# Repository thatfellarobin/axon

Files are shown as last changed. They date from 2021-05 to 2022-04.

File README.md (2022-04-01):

# Axon
[][cc-by-nc-sa]

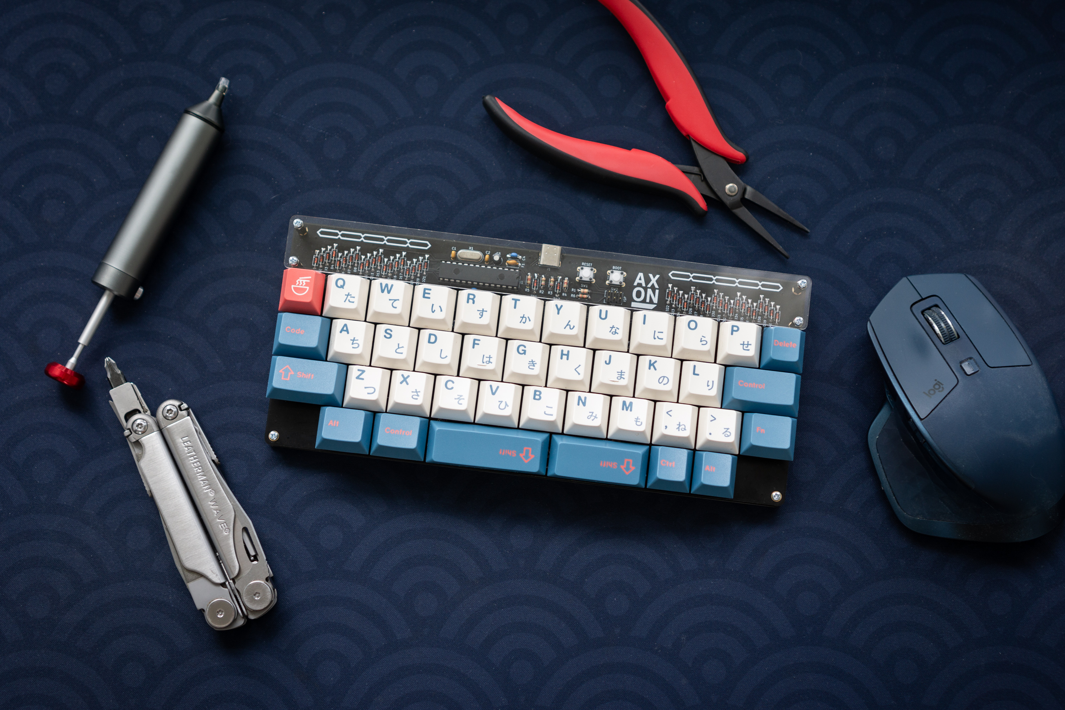
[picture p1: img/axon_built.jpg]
Built Axon

*Axon version 1.0 built with Durock T1 and GMK Bento*

⚠️ **Using the live github version is not recommended. Please use [a release](https://github.com/thatfellarobin/axon/releases) instead. Performance is not guaranteed outside of official sale (which have not existed so far).**

Axon is a 40% custom mechanical keyboard with an emphasis on symmetrically placed through-hole components, inspired by other keyboards such as [gingham](https://github.com/yiancar/gingham_pcb) and [plaid](https://github.com/hsgw/plaid). Axon runs on an ATmega328P using VUSB and QMK.

Notable features include an [HHKB-style](https://happyhackingkb.com/) layout with missing lower corners, and a split spacebar. I never use my right thumb to hit spacebar, so the split allows me to use my right thumb to access additional keyboard layers. A full write-up can be found [on my website](https://www.robinliu.me/axon).

### Images

**Layout:**

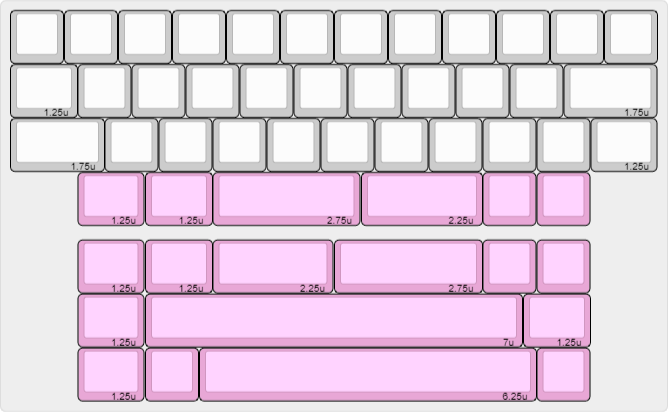
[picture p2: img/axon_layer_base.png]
Layout


**PCB EDA Screenshot:**

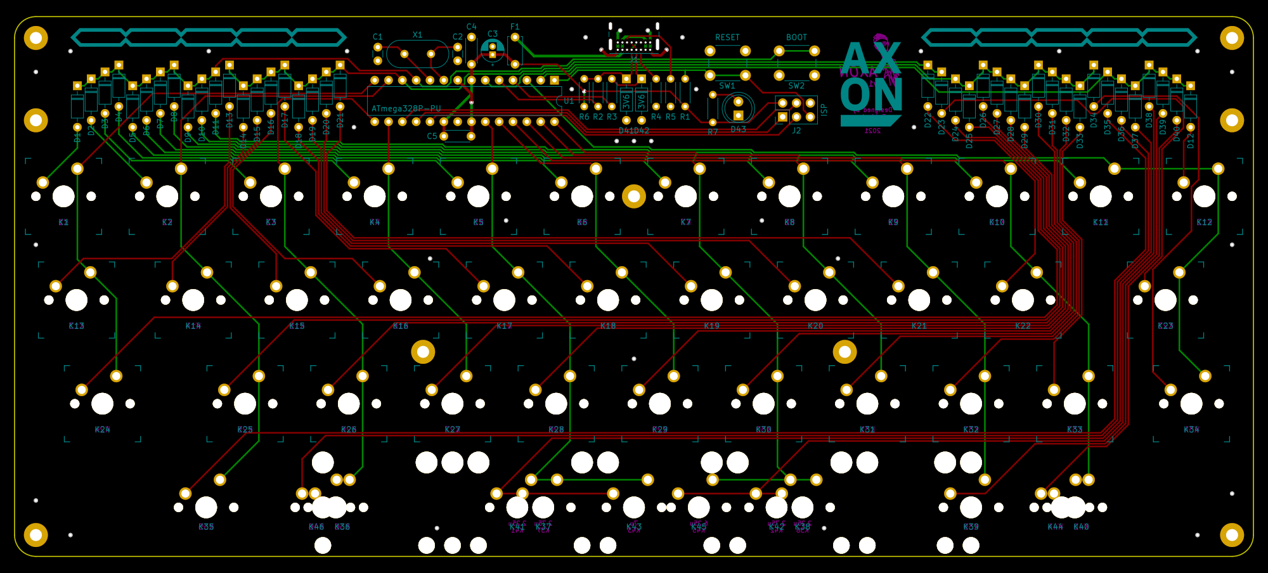
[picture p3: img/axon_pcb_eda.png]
PCB EDA Screenshot


### Component Libraries

**Symbols:**
- [Keyboard symbols by Hasu](https://github.com/tmk/kicad_lib_tmk)

**Footprints:**
- [Keyswitches by Daprice](https://github.com/daprice/keyswitches.pretty), but modified for my own tastes/uses.
- My own footprints for silkscreen art. Can be found in `lib/`

### Versions
**1.0:**
- Initial release, production version for personal use.

**1.1:**
- Spacebar widths can be swapped (i.e. 2.25u-2.75u instead of 2.75u-2.25u).
- Added support for 7u and 6.25u spacebars.
- Art is now exposed copper instead of silkscreen.
- Added an indicator LED, which is controlled through QMK as a backlight. This is to enable hardware PWM dimming.
- Update screw placements to ensure acrylic cover symmetry along both x and y axis.
- Fixed issues with stabilizer interference.
- Optimize decoupling capacitor placement.
- Polyfuse now has room to lay horizontally if desired.
- Back side silkscreen accurately reflects default layout.
- Connected shield to ground.
- Numerous minor layout and routing changes.
- Added version number to rear silkscreen.
- Updated license.

## License
This work is licensed under a
[Creative Commons Attribution-NonCommercial-ShareAlike 4.0 International License][cc-by-nc-sa].

[][cc-by-nc-sa]

[cc-by-nc-sa]: http://creativecommons.org/licenses/by-nc-sa/4.0/
[cc-by-nc-sa-image]: https://licensebuttons.net/l/by-nc-sa/4.0/88x31.png
[cc-by-nc-sa-shield]: https://img.shields.io/badge/License-CC%20BY--NC--SA%204.0-lightgrey.svg

If you have built upon this project and have significantly altered the design, the non-commercial clause can be waived with explicit permission.

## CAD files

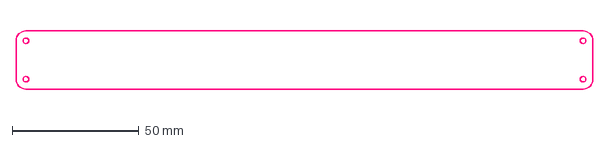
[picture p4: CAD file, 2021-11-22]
doc/axon_acryliccover.dxf
227.6 x 23.0 mm

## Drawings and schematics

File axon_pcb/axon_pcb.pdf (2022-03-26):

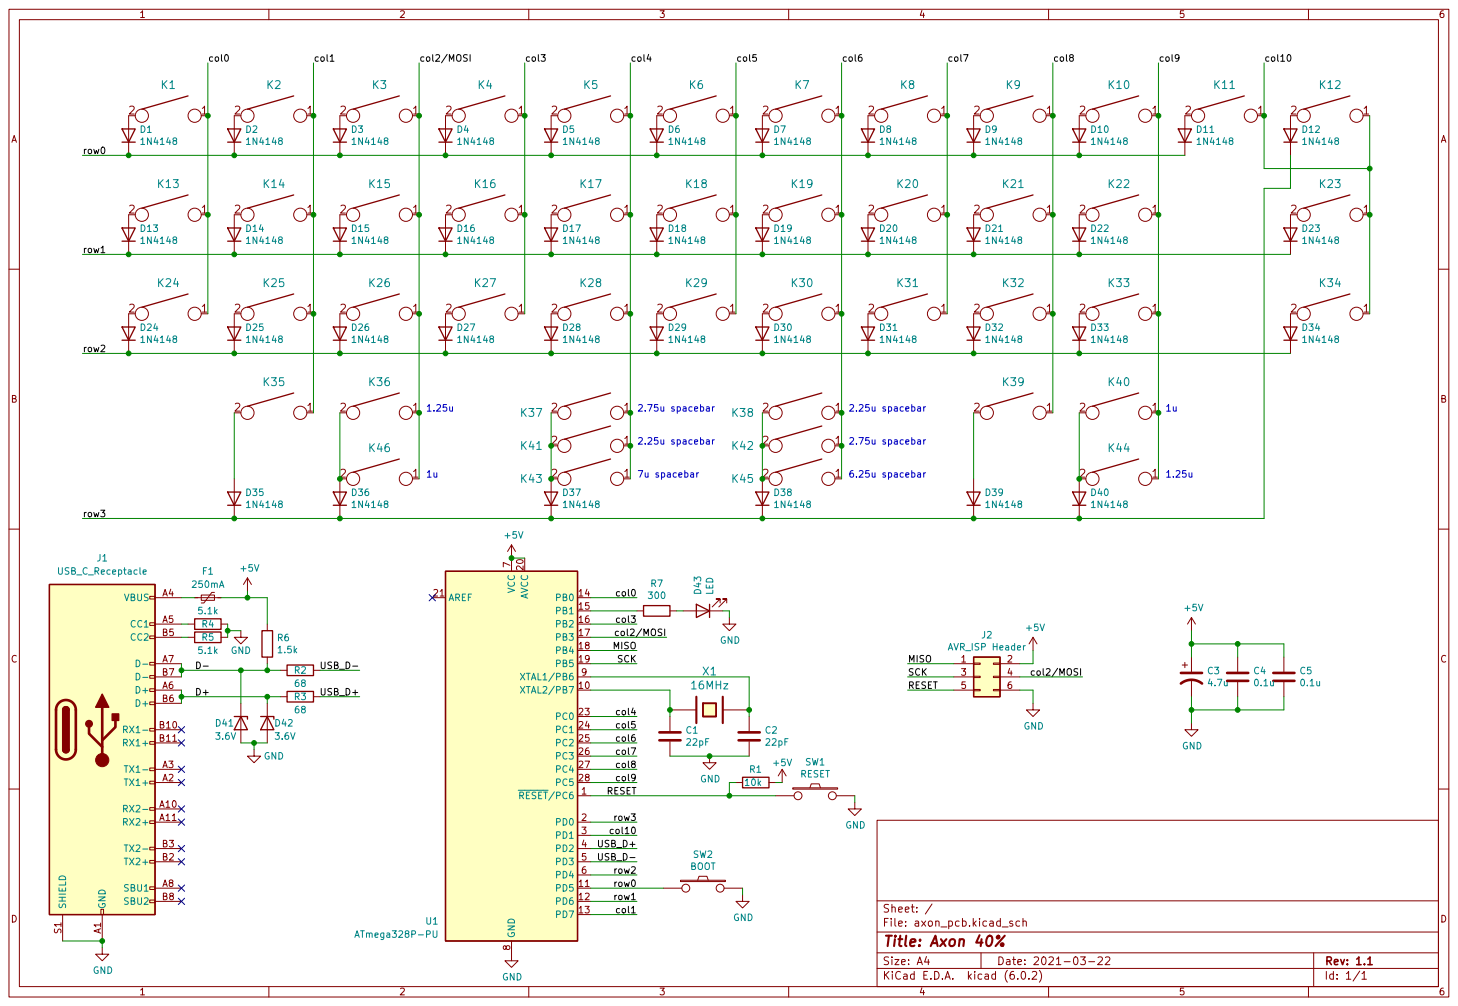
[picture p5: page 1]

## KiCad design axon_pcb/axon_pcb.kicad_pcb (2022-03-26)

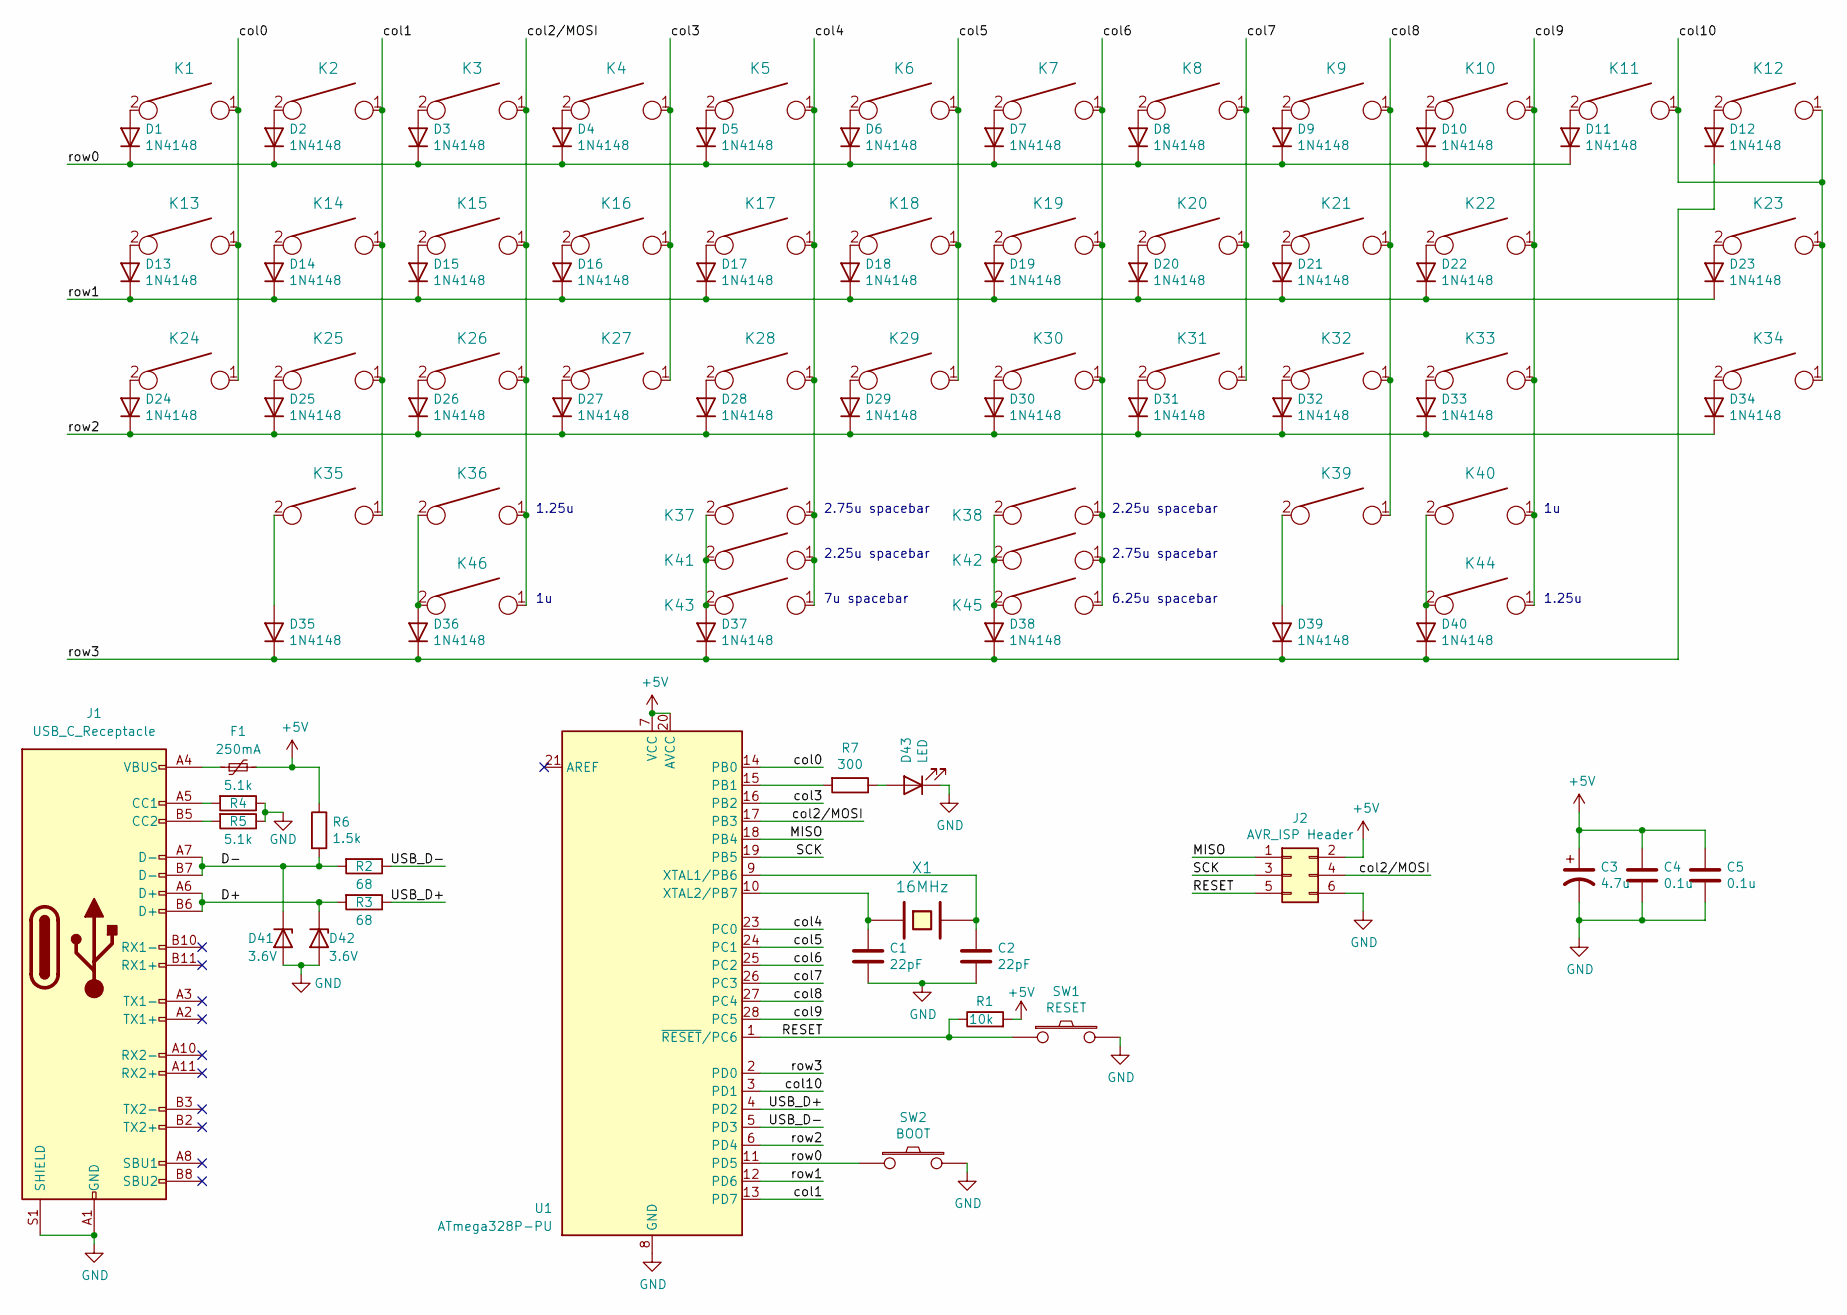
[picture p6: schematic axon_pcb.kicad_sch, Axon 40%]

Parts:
C1, C2: 22pF; C_Disc_D3.0mm_W1.6mm_P2.50mm
C3: 4.7u; CP_Radial_D4.0mm_P1.50mm
C4, C5: 0.1u; C_Disc_D4.3mm_W1.9mm_P5.00mm
D1, D2, D3, D4, D5, D6, D7, D8, D9, D10, D11, D12, D13, D14, D15, D16, D17, D18, D19, D20, D21, D22, D23, D24, D25, D26, D27, D28, D29, D30, D31, D32, D33, D34, D35, D36, D37, D38, D39, D40: 1N4148; D_DO-35_SOD27_P7.62mm_Horizontal_personal
D41, D42: 3.6V; D_DO-35_SOD27_P7.62mm_Horizontal_personal
D43: LED; LED_D5.0mm
F1: 250mA; C_Disc_D5.0mm_W2.5mm_P5.00mm
J1: USB_C_Receptacle; USB_C_Receptacle_GCT_USB4085_personalized
J2: AVR_ISP Header; PinHeader_2x03_P2.54mm_Vertical
K1, K2, K3, K4, K5, K6, K7, K8, K9, K10, K11, K12, K13, K14, K15, K16, K17, K18, K19, K20, K21, K22, K23, K24, K25, K26, K27, K28, K29, K30, K31, K32, K33, K34: KEYSW; SW_MX_InsideSilkRef
K35, K36, K37, K38, K39, K40, K41, K42, K43, K44, K45, K46: KEYSW; SW_MX_Minimal_InsideSilkRef
R1: 10k; R_Axial_DIN0204_L3.6mm_D1.6mm_P5.08mm_Horizontal
R2, R3: 68; R_Axial_DIN0204_L3.6mm_D1.6mm_P5.08mm_Horizontal
R4, R5: 5.1k; R_Axial_DIN0204_L3.6mm_D1.6mm_P5.08mm_Horizontal
R6: 1.5k; R_Axial_DIN0204_L3.6mm_D1.6mm_P5.08mm_Horizontal
R7: 300; R_Axial_DIN0204_L3.6mm_D1.6mm_P5.08mm_Horizontal
SW1: RESET; SW_PUSH_6mm
SW2: BOOT; SW_PUSH_6mm
U1: ATmega328P-PU; DIP-28_W7.62mm
X1: 16MHz; Crystal_HC49-4H_Vertical

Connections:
+5V: C3.1, C4.1, C5.1, F1.2, J2.2, R1.2, R6.1, U1.7 (VCC), U1.20 (AVCC)
/D+: D42.1 (K), J1.A6 (D+), J1.B6 (D+), R3.2
/D-: D41.1 (K), J1.A7 (D-), J1.B7 (D-), R2.2, R6.2
/MISO: J2.1, U1.18 (PB4)
/RESET: J2.5, R1.1, SW1.1, U1.1 (~RESET/PC6)
/SCK: J2.3, U1.19 (PB5)
/USB_D+: R3.1, U1.4 (PD2)
/USB_D-: R2.1, U1.5 (PD3)
/col0: K1.1, K13.1, K24.1, U1.14 (PB0)
/col1: K2.1, K14.1, K25.1, K35.1, U1.13 (PD7)
/col2/MOSI: J2.4, K3.1, K15.1, K26.1, K36.1, K46.1, U1.17 (PB3)
/col3: K4.1, K16.1, K27.1, U1.16 (PB2)
/col4: K5.1, K17.1, K28.1, K37.1, K41.1, K43.1, U1.23 (PC0)
/col5: K6.1, K18.1, K29.1, U1.24 (PC1)
/col6: K7.1, K19.1, K30.1, K38.1, K42.1, K45.1, U1.25 (PC2)
/col7: K8.1, K20.1, K31.1, U1.26 (PC3)
/col8: K9.1, K21.1, K32.1, K39.1, U1.27 (PC4)
/col9: K10.1, K22.1, K33.1, K40.1, K44.1, U1.28 (PC5)
/col10: K11.1, K12.1, K23.1, K34.1, U1.3 (PD1)
/row0: D1.1 (K), D2.1 (K), D3.1 (K), D4.1 (K), D5.1 (K), D6.1 (K), D7.1 (K), D8.1 (K), D9.1 (K), D10.1 (K), D11.1 (K), SW2.1, U1.11 (PD5)
/row1: D13.1 (K), D14.1 (K), D15.1 (K), D16.1 (K), D17.1 (K), D18.1 (K), D19.1 (K), D20.1 (K), D21.1 (K), D22.1 (K), D23.1 (K), U1.12 (PD6)
/row2: D24.1 (K), D25.1 (K), D26.1 (K), D27.1 (K), D28.1 (K), D29.1 (K), D30.1 (K), D31.1 (K), D32.1 (K), D33.1 (K), D34.1 (K), U1.6 (PD4)
/row3: D12.1 (K), D35.1 (K), D36.1 (K), D37.1 (K), D38.1 (K), D39.1 (K), D40.1 (K), U1.2 (PD0)
GND: C1.2, C2.2, C3.2, C4.2, C5.2, D41.2 (A), D42.2 (A), D43.1 (K), J1.A1 (GND), J1.A12 (GND), J1.B1 (GND), J1.B12 (GND), J1.S1 (SHIELD), J2.6, R4.1, R5.1, SW1.2, SW2.2, U1.8 (GND), U1.22 (GND)
unnamed: C1.1, U1.10 (XTAL2/PB7), X1.1
unnamed: C2.1, U1.9 (XTAL1/PB6), X1.2
unnamed: D1.2 (A), K1.2
unnamed: D2.2 (A), K2.2
unnamed: D3.2 (A), K3.2
unnamed: D4.2 (A), K4.2
unnamed: D5.2 (A), K5.2
unnamed: D6.2 (A), K6.2
unnamed: D7.2 (A), K7.2
unnamed: D8.2 (A), K8.2
unnamed: D9.2 (A), K9.2
unnamed: D10.2 (A), K10.2
unnamed: D11.2 (A), K11.2
unnamed: D12.2 (A), K12.2
unnamed: D13.2 (A), K13.2
unnamed: D14.2 (A), K14.2
unnamed: D15.2 (A), K15.2
unnamed: D16.2 (A), K16.2
unnamed: D17.2 (A), K17.2
unnamed: D18.2 (A), K18.2
unnamed: D19.2 (A), K19.2
unnamed: D20.2 (A), K20.2
unnamed: D21.2 (A), K21.2
unnamed: D22.2 (A), K22.2
unnamed: D23.2 (A), K23.2
unnamed: D24.2 (A), K24.2
unnamed: D25.2 (A), K25.2
unnamed: D26.2 (A), K26.2
unnamed: D27.2 (A), K27.2
unnamed: D28.2 (A), K28.2
unnamed: D29.2 (A), K29.2
unnamed: D30.2 (A), K30.2
unnamed: D31.2 (A), K31.2
unnamed: D32.2 (A), K32.2
unnamed: D33.2 (A), K33.2
unnamed: D34.2 (A), K34.2
unnamed: D35.2 (A), K35.2
unnamed: D36.2 (A), K36.2, K46.2
unnamed: D37.2 (A), K37.2, K41.2, K43.2
unnamed: D38.2 (A), K38.2, K42.2, K45.2
unnamed: D39.2 (A), K39.2
unnamed: D40.2 (A), K40.2, K44.2
unnamed: D43.2 (A), R7.1
unnamed: F1.1, J1.A4 (VBUS), J1.A9 (VBUS), J1.B4 (VBUS), J1.B9 (VBUS)
unnamed: J1.A5 (CC1), R4.2
unnamed: J1.B5 (CC2), R5.2
unnamed: R7.2, U1.15 (PB1)

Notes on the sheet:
1.25u
2.75u spacebar
6.25u spacebar
2.25u spacebar
7u spacebar

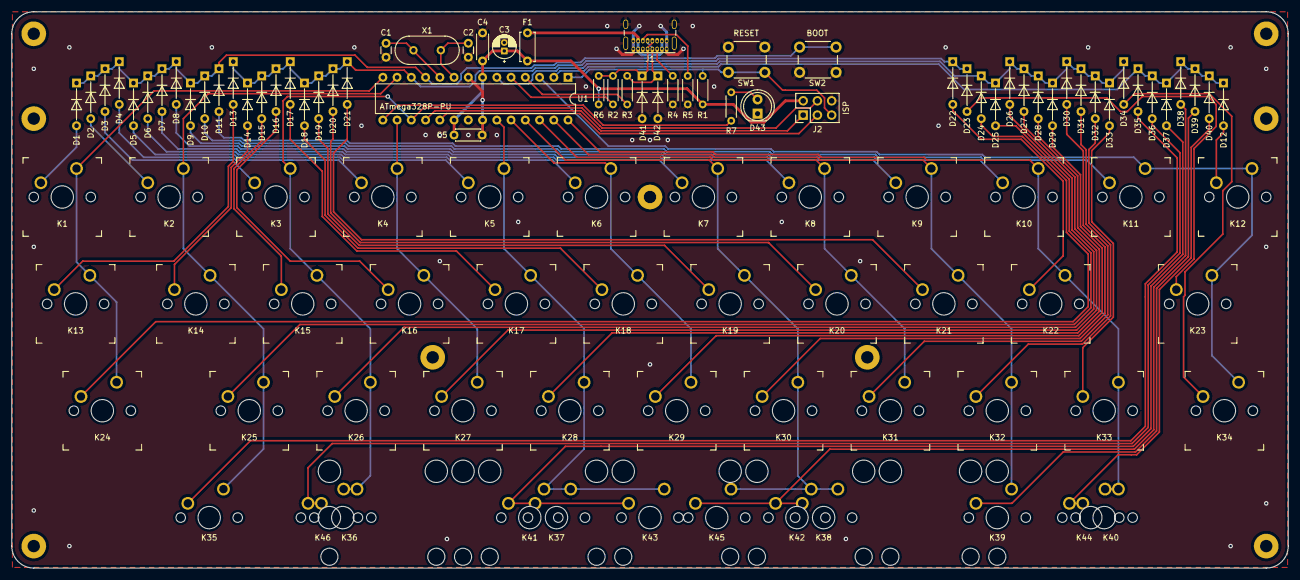
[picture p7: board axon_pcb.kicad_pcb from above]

Board: 2 copper layers, 227.6 x 99.2 mm, 108 parts (0 on the bottom side), 71 nets.

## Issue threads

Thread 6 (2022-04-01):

Might I suggest making a release for 1.1?

Webatron11, 2022-04-01:

thatfellarobin, 2022-04-01:
I'm still working on it. I plan to do so once it gets to that point.

Webatron11, 2022-04-01:
Oh nice, i just got confused cause the end of the readme mentioned 1.1. Any tips for putting one of these together? In interested in it for a travel board

thatfellarobin, 2022-04-01:
Depends. I can't say confidently at this point that I recommend either the 1.0 or development 1.1 versions. 1.0 evidently worked for me, but some parts of it are a little suspect if you order from cheaper fabs.

I'm interested in eventually selling some kits. However, I'm busy with real life stuff and it takes time and money to develop and test more prototypes so unfortunately it's not a priority for me at the moment. If you're a risk-accepting person, I'm like 90% sure the live GitHub version is fine but I can't say for sure since I haven't tested it myself.

Webatron11, 2022-04-01:
Ill give it a shot sooner or later and see if its good. Might put together a build guide too. Kits would be s splendid idea, especially for the any acrylic pieces

thatfellarobin, 2022-04-01:
Yeah. What I really need is to talk to someone who has experience putting together and selling kits, and to learn from them. I have no experience doing something like that so I feel like I would make a ton of mistakes if I tried on my own.

thatfellarobin, 2022-04-01:
Thanks for your interest btw! It really brightens my day to hear about people who still take an interest in this project.

Webatron11, 2022-04-01:
I think a friend mentioned it ages ago and I am hunting down a nice setup for travel/school and enjoyed the aesthetics youve put together. Is the second layer cumbersome to access often? Another keyboard nerd mentioned he wouldnt want to use the board due to it being 40%

Webatron11, 2022-04-02:
Im gonna put together a BOM and see how it costs in AUS. I will close this issue as it has gotten extremely off-topic.

Closed 2022-04-02.

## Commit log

2021-03-26 gitignore is now working
    [axon.dwg, axon_boardoutline.dxf, axon_boardref.dxf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]
2021-03-26 added libraries used, updated readme to give credit
    [axon_pcb.kicad_pcb]
2021-03-30 tweaked component placements: - components further from edges - less difference in USB data line lengths (now less than 2 mm) - made crystal cap trace lengths more samey
    [axon_pcb.kicad_pcb, axon_pcb.sch]
2021-03-31 fixed libraries, final pcb version
    [axon_bottom_pcb.kicad_pcb, axon_bottom_pcb.sch, axon_pcb.kicad_pcb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]
2021-04-12 updated capacitor placement
    [axon_pcb.kicad_pcb]
2021-04-12 added pcb photographs
2021-04-15 rerouting and added alt spacebar config
    [axon_pcb.kicad_pcb, axon_pcb.sch]
2021-04-29 board updates to fix 1.0 issues
    [axon_bottom_pcb.kicad_pcb, axon_pcb.kicad_pcb]
2021-04-29 update readme, change rear silk to reflect default keymap
    [axon_pcb.kicad_pcb]
2021-04-29 update board: acrylic fastener symmetry and elec cap placement
    [axon_pcb.kicad_pcb]
2021-04-30 update layout img
    [axon_pcb.kicad_pcb]
2021-04-30 updated bottom pcb with v2 screw holes
    [axon_bottom_pcb.kicad_pcb]
2021-04-30 numerous minor layout and routing tweaks
    [axon_pcb.kicad_pcb]
2021-05-02 central holes repositioned, rm one hole
    [axon_pcb.kicad_pcb]
2021-05-05 update bottom pcb
    [axon_bottom_pcb.kicad_pcb]
2021-05-06 adjust silkscreen
    [axon_pcb.kicad_pcb]
2021-05-06 added acrylic cover dxf
    [axon_acryliccover.dxf]
2021-05-06 added 7u support
    [axon_pcb.kicad_pcb, axon_pcb.sch]
2021-05-06 adjusted footprints, added 6.25u support
    [axon_pcb.kicad_pcb, axon_pcb.sch]
2021-05-06 updated usb4085 footprint for easier handsoldering, added spacebar notes to schema
    [axon_pcb.kicad_pcb, axon_pcb.sch]
2021-05-06 minor routing and position adjustments
    [axon_pcb.kicad_pcb]
2021-05-07 minor edits
    [axon_pcb.kicad_pcb]
2021-05-10 minor pcb edits
    [axon_pcb.kicad_pcb]
2021-05-10 add dimensions to pcb editor
    [axon_bottom_pcb.kicad_pcb, axon_pcb.kicad_pcb]
2021-05-11 documentation updates
    [axon_pcb.kicad_pcb]
2021-05-12 minor layout tweaks
    - Increased compactness of components below USB connector
    - Reduced length mismatch of USB data lines
    [axon_pcb.kicad_pcb, axon_pcb.sch]
2021-05-12 minor routing change
    - USB data line forced to pass directly through zener
    [axon_pcb.kicad_pcb]
2021-05-12 minor grounding improvements
    [axon_pcb.kicad_pcb]
2021-11-21 minor routing changes
    [axon_pcb.kicad_pcb, axon_pcb.sch]
2021-11-22 change resistor value
    [axon_pcb.kicad_pcb, axon_pcb.sch]
2021-11-22 slight position and shape changes
    - matched corner rounding to hole position
    - tweaked crystal caps position to be symmetric about crystal
    - tweaked hole positions to be more accurate
    [axon_acryliccover.dxf, axon_pcb.kicad_pcb, axon_pcb.sch]
2021-11-28 add power LED
    [axon_pcb.kicad_pcb, axon_pcb.sch]
2022-03-05 update kicad screenshot to 1.1
2022-03-05 update rear pcb outline
    and updated .gitignore while I was at it.
    [axon_bottom_pcb.kicad_pcb, axon_pcb.kicad_pcb, axon_pcb.kicad_sch]
2022-03-05 update deprecated files after update to KiCAD 6.0
    [axon_pcb.sch]
2022-03-05 change rear silk to show keyswitch numbers
    and make the schematic a little neater
    [axon_pcb.kicad_pcb, axon_pcb.kicad_sch]
2022-03-12 changed some silkscreen to bare copper
    - also adjusted usb connector position to be lower, sticking out from
    the board less
    [axon_bottom_pcb.kicad_sch, axon_bottom_pcb.sch, axon_pcb.kicad_pcb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]
2022-03-21 connect shield to ground
    [axon_pcb.kicad_pcb, axon_pcb.kicad_sch]
2022-03-22 adjust diode footprint, and LED connection
    - diode footprint changed to prettier symbol
    - LED now software-controlled
    [axon_pcb.kicad_pcb, axon_pcb.kicad_sch]
2022-03-26 enable hardware pwm led dimming
    [axon_pcb.kicad_pcb, axon_pcb.kicad_sch]

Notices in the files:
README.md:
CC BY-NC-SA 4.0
